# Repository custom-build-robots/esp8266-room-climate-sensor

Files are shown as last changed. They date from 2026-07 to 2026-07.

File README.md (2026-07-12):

# ESP8266 Room Climate Sensor

A WiFi room climate sensor based on the ESP8266 (NodeMCU / Wemos D1 Mini) and
one or two DHT22 sensors, featuring an SSD1306 OLED display, a live web UI,
a JSON REST API and optional MQTT support with Home Assistant discovery.

ESP8266 room climate sensor with DHT22 sensor and OLED display in 3D-printed enclosures

**Features**

- Automatic detection of one or two connected DHT22 sensors
- OLED display showing device name, temperature, humidity and IP address
- Live web interface with dark mode, auto-refreshing every 3 seconds
- Per-sensor temperature offset calibration in 0.1 °C steps, stored
  persistently in EEPROM
- REST API (`/api`) with corrected and raw values, offset, RSSI and uptime
- Captive portal WiFi setup: the sensor opens its own hotspot, lets you scan
  for networks and stores the credentials. No hardcoded WiFi credentials or
  device names in the source code
- Device name configurable via the web UI (used as hostname and mDNS address,
  e.g. `http://livingroom.local`)
- Optional MQTT support with Home Assistant discovery: configure the broker
  via the web UI and the sensor automatically appears as a device in Home
  Assistant, including availability status (last will). Leave the broker
  field empty to disable MQTT completely
- Self-healing: automatically reconnects if WiFi or the MQTT broker become
  available again

This sensor is the first building block of a DIY smart floor heating system:
one sensor per room provides the actual temperatures for a central controller
that will drive the heating valve actuators (coming in a future project).

## Repository structure

- `esp8266_dht22_oled_offset_setup_mqtt.ino` is the current full version of
  the firmware (web UI, REST API, offset calibration, WiFi setup portal and
  MQTT with Home Assistant discovery). Use this file if you build the sensor
- The other `.ino` files are earlier development stages and are kept for
  reference
- `3d_print/` contains the STL files for the 3D-printed enclosure shown in
  the photo above

## Required libraries

Install via the Arduino Library Manager:

- DHT sensor library (Adafruit)
- Adafruit Unified Sensor
- Adafruit GFX Library
- Adafruit SSD1306
- PubSubClient (Nick O'Leary), only needed for MQTT

## Build guide

**Full build guide** (in German) with photos, wiring, 3D-printed enclosure and
setup instructions on my blog:

👉 https://www.byteyourlife.com/do-it-yourself/esp8266-raumklima-sensor-mit-dht22-fussbodenheizung-smart-machen/10413

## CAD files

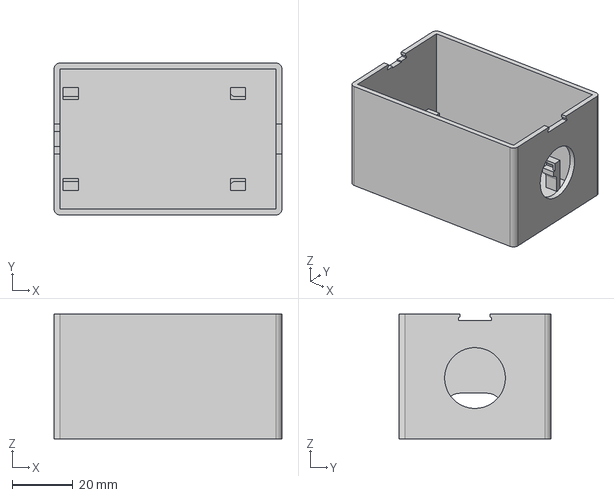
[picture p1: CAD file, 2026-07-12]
3d_print/ESP8266-case.step
75.0 x 50.0 x 41.0 mm

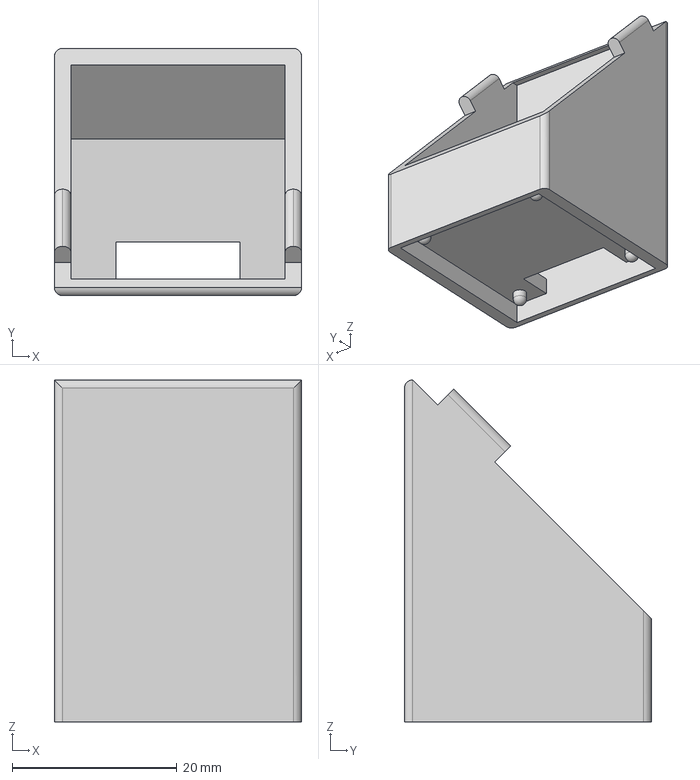
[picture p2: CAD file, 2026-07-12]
3d_print/ESP8266_OLED_mount.step.step
30.0 x 30.0 x 41.5 mm

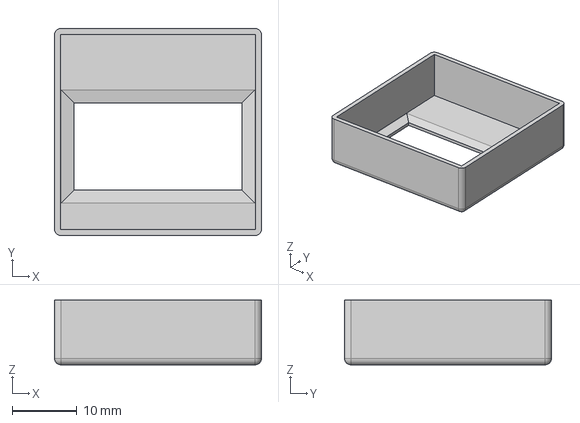
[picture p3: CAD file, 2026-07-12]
3d_print/ESP8266_OLED_cover.step
32.0 x 32.0 x 10.0 mm

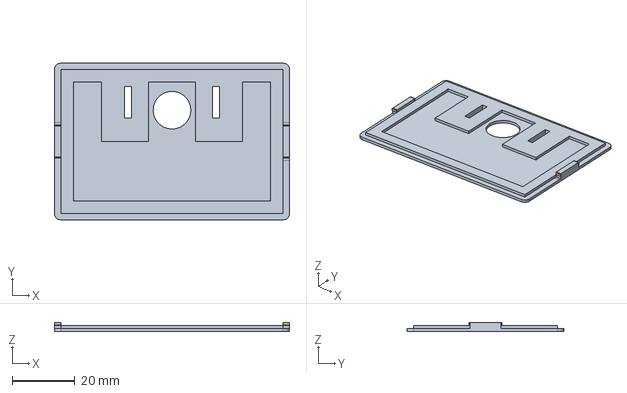
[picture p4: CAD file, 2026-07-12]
3d_print/ESP8266_cover.step
75.0 x 50.0 x 3.00 mm

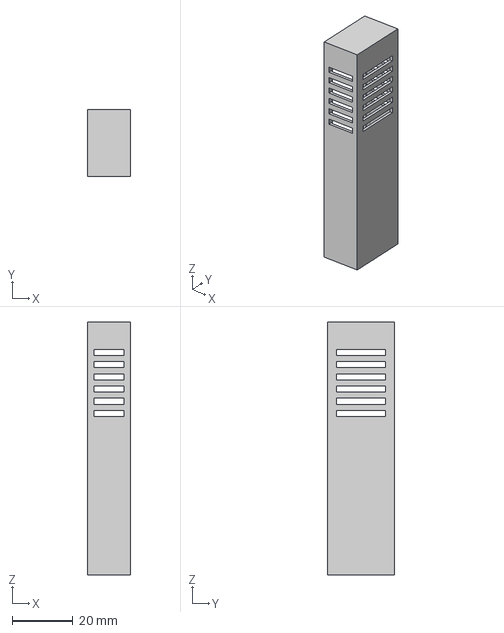
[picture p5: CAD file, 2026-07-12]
3d_print/ESP8266_sensor_mount_cover_box_DHT22.step
14.0 x 22.0 x 83.0 mm

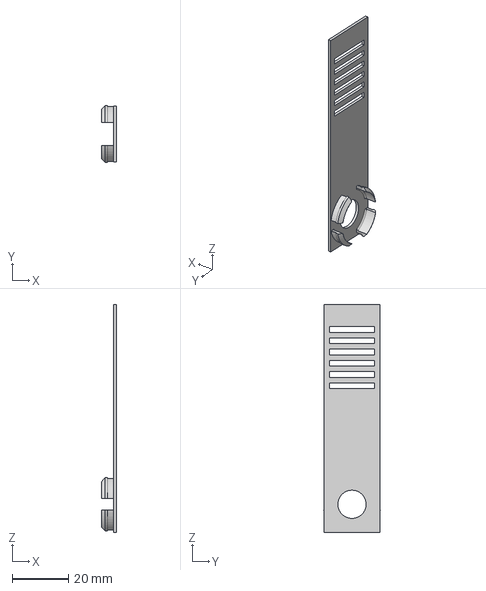
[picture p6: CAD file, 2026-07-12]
3d_print/ESP8266_sensor_mount_cover_box_mount_DHT22.step
5.20 x 20.1 x 80.8 mm

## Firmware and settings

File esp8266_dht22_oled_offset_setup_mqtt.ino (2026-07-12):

/*
 * ESP8266 – 1-2x DHT22 + OLED + REST-API + Offset + WLAN-Setup + MQTT/HA
 * ----------------------------------------------------------------------
 * NEU in dieser Version:
 *  - Optionale MQTT-Anbindung mit Home Assistant Discovery:
 *    Broker, Port, Benutzer und Passwort werden ueber die Setup-Seite
 *    konfiguriert und persistent im EEPROM gespeichert.
 *    Broker-Feld leer = MQTT komplett deaktiviert (alles laeuft wie bisher).
 *  - Der Sensor erscheint in Home Assistant automatisch als Geraet mit
 *    Entitaeten fuer Temperatur, Luftfeuchtigkeit (je Sensor) und RSSI.
 *  - Availability via Last Will: HA zeigt "nicht verfuegbar", wenn der
 *    Sensor ausfaellt.
 *  - Web-Oberflaeche, REST-API, Offset-Kalibrierung und WLAN-Setup
 *    bleiben vollstaendig unveraendert erhalten.
 *
 * Endpunkte:
 *    http://<IP>/            -> Live-Webseite (Sensorwerte + Offsets)
 *    http://<IP>/setup       -> Einstellungen (Name, WLAN, MQTT)
 *    http://<IP>/api         -> JSON fuer eigene Anwendungen
 *    http://<IP>/api/offset  -> Offset setzen (sensor=1|2, delta|set)
 *    http://<IP>/api/scan    -> WLAN-Scan als JSON
 *    http://<IP>/api/config  -> Name/WLAN/MQTT speichern (POST) -> Neustart
 *    http://<name>.local     -> per mDNS
 *
 * Benoetigte Bibliotheken (Library Manager):
 *   - "DHT sensor library" (Adafruit)
 *   - "Adafruit Unified Sensor"
 *   - "Adafruit GFX Library"
 *   - "Adafruit SSD1306"
 *   - "PubSubClient" (Nick O'Leary)          <- NEU fuer MQTT
 */

#include <ESP8266WiFi.h>
#include <ESP8266WebServer.h>
#include <ESP8266mDNS.h>
#include <DNSServer.h>
#include <EEPROM.h>
#include <Wire.h>
#include <Adafruit_GFX.h>
#include <Adafruit_SSD1306.h>
#include <DHT.h>
#include <PubSubClient.h>

// ---------------- Setup-Hotspot ----------------
// Leer = offener Hotspot. Wenn gesetzt, mindestens 8 Zeichen!
const char* AP_PASSWORD  = "";
const char* DEFAULT_NAME = "Klima-Sensor";
const char* SW_VERSION   = "1.1";

// ---------------- MQTT ----------------
const char* HA_DISCOVERY_PREFIX = "homeassistant";   // HA-Standard
const unsigned long MQTT_PUBLISH_INTERVAL   = 30000; // Werte alle 30 s
const unsigned long MQTT_RECONNECT_INTERVAL = 15000; // Reconnect alle 15 s

// ---------------- DHT22 ----------------
#define DHTTYPE DHT22
#define DHTPIN1 14   // D5  -> DHT22 Sensor 1
#define DHTPIN2 12   // D6  -> DHT22 Sensor 2
DHT dht1(DHTPIN1, DHTTYPE);
DHT dht2(DHTPIN2, DHTTYPE);

// ---------------- OLED SSD1306 ----------------
#define SCREEN_WIDTH  128
#define SCREEN_HEIGHT 64     // bei 128x32-Display hier auf 32 aendern
#define OLED_RESET    -1
#define OLED_ADDR     0x3C   // ggf. 0x3D
#define I2C_SDA       4      // D2
#define I2C_SCL       5      // D1
Adafruit_SSD1306 display(SCREEN_WIDTH, SCREEN_HEIGHT, &Wire, OLED_RESET);

// ---------------- Webserver / DNS / MQTT ----------------
ESP8266WebServer server(80);
DNSServer dnsServer;
WiFiClient espClient;
PubSubClient mqtt(espClient);
bool apMode = false;
String apSsid;
String chipIdStr;          // eindeutige ID aus der Chip-ID (hex)
unsigned long lastMqttPublish = 0;
unsigned long lastMqttAttempt = 0;
bool discoveryPublished = false;

// ---------------- Persistente Konfiguration ----------------
// Version 3: Name + WLAN + Offsets + MQTT.
// Offsets in ZEHNTELGRAD (int16). 3 == +0.3 C
struct PersistData {
  uint32_t magic;
  char     name[32];      // Geraetename
  char     ssid[33];      // WLAN-SSID
  char     pass[64];      // WLAN-Passwort
  int16_t  offT1;         // Offset Sensor 1 in 0.1 C
  int16_t  offT2;         // Offset Sensor 2 in 0.1 C
  char     mqttHost[41];  // MQTT-Broker (leer = MQTT deaktiviert)
  uint16_t mqttPort;      // MQTT-Port (0 -> 1883)
  char     mqttUser[33];  // MQTT-Benutzer (optional)
  char     mqttPass[41];  // MQTT-Passwort (optional)
};
// Alte Strukturen fuer die Migration:
struct PersistDataV2 {
  uint32_t magic;
  char     name[32];
  char     ssid[33];
  char     pass[64];
  int16_t  offT1;
  int16_t  offT2;
};
struct PersistDataV1 {
  uint32_t magic;
  int16_t  offT1;
  int16_t  offT2;
};
const uint32_t EE_MAGIC_V1 = 0x44485432;   // "DHT2"
const uint32_t EE_MAGIC_V2 = 0x44485433;   // "DHT3"
const uint32_t EE_MAGIC_V3 = 0x44485434;   // "DHT4" (aktuell)
const int16_t  OFFSET_MIN  = -100;         // -10.0 C
const int16_t  OFFSET_MAX  =  100;         // +10.0 C

PersistData cfg;

void saveConfig() {
  cfg.magic = EE_MAGIC_V3;
  EEPROM.put(0, cfg);
  EEPROM.commit();   // beim ESP8266 zwingend noetig!
  Serial.println("Konfiguration gespeichert.");
}

void loadConfig() {
  EEPROM.begin(512);
  EEPROM.get(0, cfg);

  if (cfg.magic == EE_MAGIC_V3) {
    cfg.name[sizeof(cfg.name) - 1]         = '\0';
    cfg.ssid[sizeof(cfg.ssid) - 1]         = '\0';
    cfg.pass[sizeof(cfg.pass) - 1]         = '\0';
    cfg.mqttHost[sizeof(cfg.mqttHost) - 1] = '\0';
    cfg.mqttUser[sizeof(cfg.mqttUser) - 1] = '\0';
    cfg.mqttPass[sizeof(cfg.mqttPass) - 1] = '\0';
    cfg.offT1 = constrain(cfg.offT1, OFFSET_MIN, OFFSET_MAX);
    cfg.offT2 = constrain(cfg.offT2, OFFSET_MIN, OFFSET_MAX);
    Serial.printf("Konfig geladen: Name='%s' SSID='%s' MQTT='%s' Offsets S1=%+.1f S2=%+.1f\n",
                  cfg.name, cfg.ssid, cfg.mqttHost,
                  cfg.offT1 / 10.0f, cfg.offT2 / 10.0f);
    return;
  }

  if (cfg.magic == EE_MAGIC_V2) {
    // Migration V2 -> V3: alles uebernehmen, MQTT-Felder leer
    PersistDataV2 old;
    EEPROM.get(0, old);
    memset(&cfg, 0, sizeof(cfg));
    memcpy(cfg.name, old.name, sizeof(cfg.name));
    memcpy(cfg.ssid, old.ssid, sizeof(cfg.ssid));
    memcpy(cfg.pass, old.pass, sizeof(cfg.pass));
    cfg.name[sizeof(cfg.name) - 1] = '\0';
    cfg.ssid[sizeof(cfg.ssid) - 1] = '\0';
    cfg.pass[sizeof(cfg.pass) - 1] = '\0';
    cfg.offT1 = constrain(old.offT1, OFFSET_MIN, OFFSET_MAX);
    cfg.offT2 = constrain(old.offT2, OFFSET_MIN, OFFSET_MAX);
    saveConfig();
    Serial.println("EEPROM von V2 migriert (Name/WLAN/Offsets uebernommen).");
    return;
  }

  if (cfg.magic == EE_MAGIC_V1) {
    // Migration V1 -> V3: nur Offsets vorhanden
    PersistDataV1 old;
    EEPROM.get(0, old);
    memset(&cfg, 0, sizeof(cfg));
    strlcpy(cfg.name, DEFAULT_NAME, sizeof(cfg.name));
    cfg.offT1 = constrain(old.offT1, OFFSET_MIN, OFFSET_MAX);
    cfg.offT2 = constrain(old.offT2, OFFSET_MIN, OFFSET_MAX);
    saveConfig();
    Serial.println("EEPROM von V1 migriert (Offsets uebernommen).");
    return;
  }

  // Erststart: Defaults
  memset(&cfg, 0, sizeof(cfg));
  strlcpy(cfg.name, DEFAULT_NAME, sizeof(cfg.name));
  saveConfig();
  Serial.println("EEPROM initialisiert (Defaults).");
}

bool mqttConfigured() { return strlen(cfg.mqttHost) > 0; }
uint16_t getMqttPort() { return cfg.mqttPort ? cfg.mqttPort : 1883; }

// ---------------- Messwerte ----------------
struct Reading {
  float temperature = NAN;   // korrigierter Wert (roh + Offset)
  float rawTemp     = NAN;   // Rohwert vom Sensor
  float humidity    = NAN;
  bool  valid       = false; // letzte Messung erfolgreich?
  bool  present     = false; // Sensor ueberhaupt angeschlossen?
};
Reading r1, r2;

// ---------------- Explizite Prototypen ----------------
// Noetig, weil die Arduino IDE ihre Auto-Prototypen VOR der
// Struct-Definition einfuegt -> "Reading has not been declared".
void readOne(DHT& dht, Reading& r, int16_t offsetTenths);
void appendSensor(char* buf, size_t n, const char* key,
                  const Reading& r, int16_t offsetTenths);

String hostName;  // aus cfg.name erzeugter, DNS-tauglicher Name

unsigned long lastMeasure = 0;
const unsigned long MEASURE_INTERVAL   = 5000;                // alle 5 s messen
const unsigned long AP_RETRY_INTERVAL  = 5UL * 60UL * 1000UL; // 5 min
unsigned long apStarted = 0;

// ---------------- Hilfsfunktion: Name -> Hostname ----------------
String slugify(const String& in) {
  String out;
  for (size_t i = 0; i < in.length(); ) {
    uint8_t c = (uint8_t)in[i];
    if (c == 0xC3 && i + 1 < in.length()) {        // UTF-8 Umlaut-Praefix
      uint8_t c2 = (uint8_t)in[i + 1];
      switch (c2) {
        case 0xA4: case 0x84: out += "ae"; break;  // ä Ä
        case 0xB6: case 0x96: out += "oe"; break;  // ö Ö
        case 0xBC: case 0x9C: out += "ue"; break;  // ü Ü
        case 0x9F:            out += "ss"; break;  // ß
        default: break;
      }
      i += 2; continue;
    }
    if      (c >= 'A' && c <= 'Z') out += (char)(c - 'A' + 'a');
    else if ((c >= 'a' && c <= 'z') || (c >= '0' && c <= '9')) out += (char)c;
    else if (c == ' ' || c == '_' || c == '-') out += '-';
    i++;
  }
  while (out.length() && out[0] == '-') out.remove(0, 1);
  while (out.length() && out[out.length() - 1] == '-') out.remove(out.length() - 1);
  if (out.length() == 0) out = "esp-sensor";
  return out;
}

// ---------------- Hilfsfunktion: String fuer JSON escapen ----------------
String jsonEscape(const char* s) {
  String out;
  for (const char* p = s; *p; p++) {
    if (*p == '"' || *p == '\\') { out += '\\'; out += *p; }
    else if ((uint8_t)*p < 0x20) { out += ' '; }
    else out += *p;
  }
  return out;
}

// ---------------- OLED: einfache Textseite ----------------
void showBootScreen(const char* line1, const char* line2, const char* line3) {
  display.clearDisplay();
  display.setTextSize(1);
  display.setTextColor(SSD1306_WHITE);
  display.setCursor(0, 0);  display.println(cfg.name);
  display.drawFastHLine(0, 10, SCREEN_WIDTH, SSD1306_WHITE);
  display.setCursor(0, 18); display.println(line1);
  display.setCursor(0, 32); display.println(line2);
  display.setCursor(0, 46); display.println(line3);
  display.display();
}

// ---------------- WLAN: Verbindung versuchen ----------------
bool connectSTA() {
  if (strlen(cfg.ssid) == 0) return false;

  Serial.printf("Verbinde mit '%s'", cfg.ssid);
  showBootScreen("Verbinde mit WLAN:", cfg.ssid, "");

  WiFi.mode(WIFI_STA);
  WiFi.hostname(hostName.c_str());
  WiFi.begin(cfg.ssid, cfg.pass);

  unsigned long start = millis();
  while (WiFi.status() != WL_CONNECTED && millis() - start < 20000) {
    delay(500);
    Serial.print(".");
  }
  Serial.println();

  if (WiFi.status() == WL_CONNECTED) {
    Serial.print("WLAN verbunden - Name: "); Serial.println(hostName);
    Serial.print("WLAN verbunden - IP:   "); Serial.println(WiFi.localIP());
    Serial.print("WLAN verbunden - MAC:  "); Serial.println(WiFi.macAddress());
    return true;
  }
  Serial.println("WLAN-Verbindung fehlgeschlagen.");
  return false;
}

// ---------------- WLAN: Setup-Hotspot starten ----------------
void startAP() {
  apMode = true;
  apStarted = millis();
  apSsid = "Klima-Setup-" + chipIdStr;

  // AP_STA, damit WLAN-Scan auch im Hotspot-Modus funktioniert
  WiFi.mode(WIFI_AP_STA);
  if (strlen(AP_PASSWORD) >= 8) WiFi.softAP(apSsid.c_str(), AP_PASSWORD);
  else                          WiFi.softAP(apSsid.c_str());

  // Captive Portal: alle DNS-Anfragen auf uns umleiten
  dnsServer.start(53, "*", WiFi.softAPIP());

  Serial.printf("Setup-Hotspot aktiv: %s  ->  http://%s/\n",
                apSsid.c_str(), WiFi.softAPIP().toString().c_str());
  showBootScreen("Setup-Modus! WLAN:", apSsid.c_str(), "http://192.168.4.1");
}

// ---------------- einen Sensor lesen ----------------
void readOne(DHT& dht, Reading& r, int16_t offsetTenths) {
  float h = dht.readHumidity();
  float t = dht.readTemperature();
  if (!isnan(h) && !isnan(t)) {
    r.rawTemp     = t;
    r.temperature = t + offsetTenths / 10.0f;   // Offset anwenden
    r.humidity    = h;
    r.valid       = true;
    r.present     = true;          // einmal gelesen = vorhanden
  } else {
    r.valid = false;               // present bleibt erhalten
  }
}

void readSensors() {
  readOne(dht1, r1, cfg.offT1);
  readOne(dht2, r2, cfg.offT2);
  Serial.printf("[%s]  S1 present=%d %.1fC/%.0f%% (off %+.1f)   S2 present=%d %.1fC/%.0f%% (off %+.1f)\n",
                cfg.name,
                r1.present, r1.temperature, r1.humidity, cfg.offT1 / 10.0f,
                r2.present, r2.temperature, r2.humidity, cfg.offT2 / 10.0f);
}

// ---------------- Sensoren beim Start erkennen ----------------
void detectSensors() {
  for (int i = 0; i < 3 && !(r1.present && r2.present); i++) {
    readOne(dht1, r1, cfg.offT1);
    readOne(dht2, r2, cfg.offT2);
    if (r1.present && r2.present) break;
    delay(2000);
  }
  int n = (r1.present ? 1 : 0) + (r2.present ? 1 : 0);
  Serial.printf("Erkannte Sensoren: %d\n", n);
}

// ---------------- OLED aktualisieren ----------------
void updateDisplay() {
  if (apMode) {
    showBootScreen("Setup-Modus! WLAN:", apSsid.c_str(), "http://192.168.4.1");
    return;
  }

  display.clearDisplay();
  display.setTextColor(SSD1306_WHITE);

  display.setTextSize(1);
  display.setCursor(0, 0);
  display.println(cfg.name);
  display.drawFastHLine(0, 10, SCREEN_WIDTH, SSD1306_WHITE);

  int count = (r1.present ? 1 : 0) + (r2.present ? 1 : 0);

  if (count == 0) {
    display.setCursor(0, 26);
    display.print("Kein Sensor gefunden");
  } else if (count == 1) {
    Reading& r = r1.present ? r1 : r2;
    display.setTextSize(2);
    display.setCursor(0, 18);
    if (r.valid) display.printf("%.1f C", r.temperature);
    else         display.print("--.- C");
    display.setTextSize(1);
    display.setCursor(0, 42);
    if (r.valid) display.printf("Luftf.: %.0f %%", r.humidity);
    else         display.print("Luftf.: -- %");
  } else {
    display.setTextSize(1);
    display.setCursor(0, 16);
    if (r1.valid) display.printf("S1: %.1fC  %.0f%%", r1.temperature, r1.humidity);
    else          display.print("S1: ---");
    display.setCursor(0, 28);
    if (r2.valid) display.printf("S2: %.1fC  %.0f%%", r2.temperature, r2.humidity);
    else          display.print("S2: ---");
  }

  display.setTextSize(1);
  display.setCursor(0, 54);
  display.print(WiFi.localIP().toString());
  display.display();
}

// ================================================================
//                     MQTT / Home Assistant
// ================================================================

String mqttBaseTopic()  { return "klima/" + chipIdStr; }          // z.B. klima/a1b2c3
String mqttStateTopic() { return mqttBaseTopic() + "/state"; }
String mqttAvailTopic() { return mqttBaseTopic() + "/status"; }

// Gemeinsamer "device"-Block, damit HA alle Entitaeten gruppiert
String haDeviceJson() {
  String d = "\"dev\":{\"ids\":[\"klima_" + chipIdStr + "\"],";
  d += "\"name\":\"" + jsonEscape(cfg.name) + "\",";
  d += "\"mf\":\"DIY\",\"mdl\":\"ESP8266 Klima-Sensor\",";
  d += "\"sw\":\"" + String(SW_VERSION) + "\",";
  d += "\"cu\":\"http://" + WiFi.localIP().toString() + "/\"}";
  return d;
}

// Eine Discovery-Config fuer eine Entitaet publizieren (retained)
void publishOneDiscovery(const char* objId, const char* entName,
                         const char* devClass, const char* unit,
                         const char* valueKey, bool diagnostic) {
  String topic = String(HA_DISCOVERY_PREFIX) + "/sensor/klima_" + chipIdStr +
                 "_" + objId + "/config";

  String p = "{";
  p += "\"name\":\"" + String(entName) + "\",";
  p += "\"uniq_id\":\"klima_" + chipIdStr + "_" + objId + "\",";
  p += "\"stat_t\":\"" + mqttStateTopic() + "\",";
  p += "\"avty_t\":\"" + mqttAvailTopic() + "\",";
  p += "\"dev_cla\":\"" + String(devClass) + "\",";
  p += "\"unit_of_meas\":\"" + String(unit) + "\",";
  p += "\"stat_cla\":\"measurement\",";
  p += "\"val_tpl\":\"{{ value_json." + String(valueKey) + " }}\",";
  if (diagnostic) p += "\"ent_cat\":\"diagnostic\",";
  p += haDeviceJson();
  p += "}";

  bool ok = mqtt.publish(topic.c_str(), p.c_str(), true);   // retained!
  Serial.printf("HA-Discovery %s: %s\n", objId, ok ? "ok" : "FEHLER");
}

void publishDiscovery() {
  bool two = r1.present && r2.present;
  if (r1.present) {
    publishOneDiscovery("t1", two ? "Temperatur 1" : "Temperatur",
                        "temperature", "\u00b0C", "t1", false);
    publishOneDiscovery("h1", two ? "Luftfeuchtigkeit 1" : "Luftfeuchtigkeit",
                        "humidity", "%", "h1", false);
  }
  if (r2.present) {
    publishOneDiscovery("t2", two ? "Temperatur 2" : "Temperatur",
                        "temperature", "\u00b0C", "t2", false);
    publishOneDiscovery("h2", two ? "Luftfeuchtigkeit 2" : "Luftfeuchtigkeit",
                        "humidity", "%", "h2", false);
  }
  publishOneDiscovery("rssi", "WLAN-Signal", "signal_strength", "dBm",
                      "rssi", true);
  discoveryPublished = true;
}

// Aktuelle Messwerte publizieren
void publishState() {
  char t1[12], h1[12], t2[12], h2[12];
  dtostrf(r1.temperature, 0, 1, t1);
  dtostrf(r1.humidity,    0, 1, h1);
  dtostrf(r2.temperature, 0, 1, t2);
  dtostrf(r2.humidity,    0, 1, h2);

  String json = "{";
  if (r1.present && r1.valid) {
    json += "\"t1\":" + String(t1) + ",\"h1\":" + String(h1) + ",";
  }
  if (r2.present && r2.valid) {
    json += "\"t2\":" + String(t2) + ",\"h2\":" + String(h2) + ",";
  }
  json += "\"rssi\":" + String(WiFi.RSSI()) + ",";
  json += "\"uptime_s\":" + String(millis() / 1000UL);
  json += "}";

  mqtt.publish(mqttStateTopic().c_str(), json.c_str(), false);
}

// Verbindung zum Broker aufbauen (nicht-blockierend im Loop aufgerufen)
void mqttEnsureConnected() {
  if (mqtt.connected()) return;
  if (millis() - lastMqttAttempt < MQTT_RECONNECT_INTERVAL &&
      lastMqttAttempt != 0) return;
  lastMqttAttempt = millis();

  String clientId = "klima-" + chipIdStr;
  Serial.printf("MQTT: verbinde mit %s:%u ... ", cfg.mqttHost, getMqttPort());

  // Last Will: bei Verbindungsabbruch setzt der Broker "offline" (retained)
  bool ok;
  if (strlen(cfg.mqttUser) > 0) {
    ok = mqtt.connect(clientId.c_str(), cfg.mqttUser, cfg.mqttPass,
                      mqttAvailTopic().c_str(), 0, true, "offline");
  } else {
    ok = mqtt.connect(clientId.c_str(),
                      mqttAvailTopic().c_str(), 0, true, "offline");
  }

  if (ok) {
    Serial.println("verbunden.");
    mqtt.publish(mqttAvailTopic().c_str(), "online", true);   // retained
    publishDiscovery();
    publishState();
    lastMqttPublish = millis();
  } else {
    Serial.printf("fehlgeschlagen (rc=%d), naechster Versuch in %lus.\n",
                  mqtt.state(), MQTT_RECONNECT_INTERVAL / 1000UL);
  }
}

void mqttSetup() {
  if (!mqttConfigured()) {
    Serial.println("MQTT: kein Broker konfiguriert -> deaktiviert.");
    return;
  }
  mqtt.setServer(cfg.mqttHost, getMqttPort());
  // Discovery-Payloads sind groesser als der PubSubClient-Default (256 B)
  mqtt.setBufferSize(768);
  Serial.printf("MQTT: konfiguriert fuer %s:%u\n", cfg.mqttHost, getMqttPort());
}

// ================================================================
//                          HTTP-Handler
// ================================================================

// ---------------- JSON-API ----------------
void appendSensor(char* buf, size_t n, const char* key,
                  const Reading& r, int16_t offsetTenths) {
  char t[12], traw[12], h[12], off[12];
  dtostrf(r.temperature, 0, 1, t);
  dtostrf(r.rawTemp,     0, 1, traw);
  dtostrf(r.humidity,    0, 1, h);
  dtostrf(offsetTenths / 10.0f, 0, 1, off);
  char part[220];
  snprintf(part, sizeof(part),
    "\"%s\":{\"present\":%s,\"temperature\":%s,\"temperature_raw\":%s,"
    "\"offset\":%s,\"humidity\":%s,\"valid\":%s},",
    key,
    r.present ? "true" : "false",
    r.valid   ? t    : "null",
    r.valid   ? traw : "null",
    off,
    r.valid   ? h : "null",
    r.valid   ? "true" : "false");
  strncat(buf, part, n - strlen(buf) - 1);
}

void handleApi() {
  char buf[900];
  buf[0] = '\0';

  String nameEsc = jsonEscape(cfg.name);
  char head[120];
  snprintf(head, sizeof(head), "{\"name\":\"%s\",\"setup_mode\":%s,",
           nameEsc.c_str(), apMode ? "true" : "false");
  strncat(buf, head, sizeof(buf) - strlen(buf) - 1);

  appendSensor(buf, sizeof(buf), "sensor1", r1, cfg.offT1);
  appendSensor(buf, sizeof(buf), "sensor2", r2, cfg.offT2);

  // MQTT-Status (Passwort wird nie ausgegeben)
  String mq = "\"mqtt\":{\"enabled\":" +
              String(mqttConfigured() ? "true" : "false") +
              ",\"connected\":" + String(mqtt.connected() ? "true" : "false") +
              ",\"host\":\"" + jsonEscape(cfg.mqttHost) + "\"" +
              ",\"port\":" + String(getMqttPort()) +
              ",\"user\":\"" + jsonEscape(cfg.mqttUser) + "\"},";
  strncat(buf, mq.c_str(), sizeof(buf) - strlen(buf) - 1);

  char tail[80];
  snprintf(tail, sizeof(tail), "\"rssi\":%d,\"uptime_s\":%lu}",
           WiFi.RSSI(), millis() / 1000UL);
  strncat(buf, tail, sizeof(buf) - strlen(buf) - 1);

  server.sendHeader("Access-Control-Allow-Origin", "*");
  server.send(200, "application/json", buf);
}
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
void loop() {
  server.handleClient();

  if (apMode) {
    dnsServer.processNextRequest();

    // Wenn WLAN-Daten gespeichert sind und gerade niemand am Hotspot
    // haengt: alle 5 min neu versuchen (z.B. Router war kurz offline)
    if (strlen(cfg.ssid) > 0 &&
        millis() - apStarted > AP_RETRY_INTERVAL &&
        WiFi.softAPgetStationNum() == 0) {
      Serial.println("Erneuter WLAN-Versuch -> Neustart");
      ESP.restart();
    }
  } else {
    MDNS.update();

    // MQTT nur, wenn ein Broker konfiguriert ist
    if (mqttConfigured()) {
      mqttEnsureConnected();
      if (mqtt.connected()) {
        mqtt.loop();
        if (millis() - lastMqttPublish > MQTT_PUBLISH_INTERVAL) {
          lastMqttPublish = millis();
          publishState();
        }
      }
    }
  }

  if (millis() - lastMeasure > MEASURE_INTERVAL) {
    lastMeasure = millis();
    readSensors();
    updateDisplay();
  }
}

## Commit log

2026-07-05 Revise README for ESP8266 Room Climate Sensor
    Updated the README to provide a detailed overview of the ESP8266 Room Climate Sensor features, including setup instructions and a link to a full build guide.
2026-07-05 Add image to README for ESP8266 climate sensor
    Added an image of the ESP8266 room climate sensor to the README.
